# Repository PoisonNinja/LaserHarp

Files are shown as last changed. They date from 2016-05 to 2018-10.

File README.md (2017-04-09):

# Laser Harp
Code for creating a laser harp (school project)

# Setup
Only supported on systems with apt-get for now!
`./setup.sh`

# Usage
Connect the Arduino to the computer, and flash the code. Run `./connect.sh`, and hear the sound. 

To kill the programs, in a seperate terminal window, run `./kill.sh`. Make sure that you run this before unplugging the Arduino, or else you may experience sound glitches.

# MidiTest
A small utility to test out if MIDI is working or not.

You should hear a piano scale going upwards.

# MidiLEDSensor
Test code to control MIDI using a LED as a light sensor.

Wire a LED into the Arduino as follows:
* A5 to the short leg of the LED
* Resistor from the long leg to another part of the breadboard
* Breadboard/resistor to GND

Make sure you are in a bright room, and cover the LED. You should a piano tone.

If you want to use a different analog port, change the LEDPORT define. To change the note, change the NOTE define. To change the delay, change the DELAY define. To change the sensitivity of the LED, change the THRESHOLD define.

# MotorLaser
Code for the failed frameless harp idea. Currently is able to pulse the laser on and off in sync with the motor, drawing eight dots on the ceiling, and also has some code for reading detected sensor values. If you have a strong enough laser, this may work for you.

Wiring diagrams will have to be figured out by yourself, because I lost the diagrams.

Expected output is that it should play a note corresponding to the beam being cut.

# Guzheng
The code for our final project. The harp looks like the Chinese Guzheng, and was mainly inspired by it. It works well (assuming you built correctly), and has very little issues. It does have some latency, but it's very small.

A basic wiring diagram is available in the Guzheng folder, but it is incomplete, and you will have to figure out the rest of it.

Expected output is that it should play a note corresponding to the beam being cut.

# Harp
An experimental rewrite of the Guzheng code, except with a client-server architecture. This offloads most of the work to the computer and makes the Arduino a sensor hub, hopefully improving performance. It doesn't really work right now because it has a weird tendency to skip notes or hold on to notes too long.

Wiring diagrams and expected output are the same as the Guzheng.

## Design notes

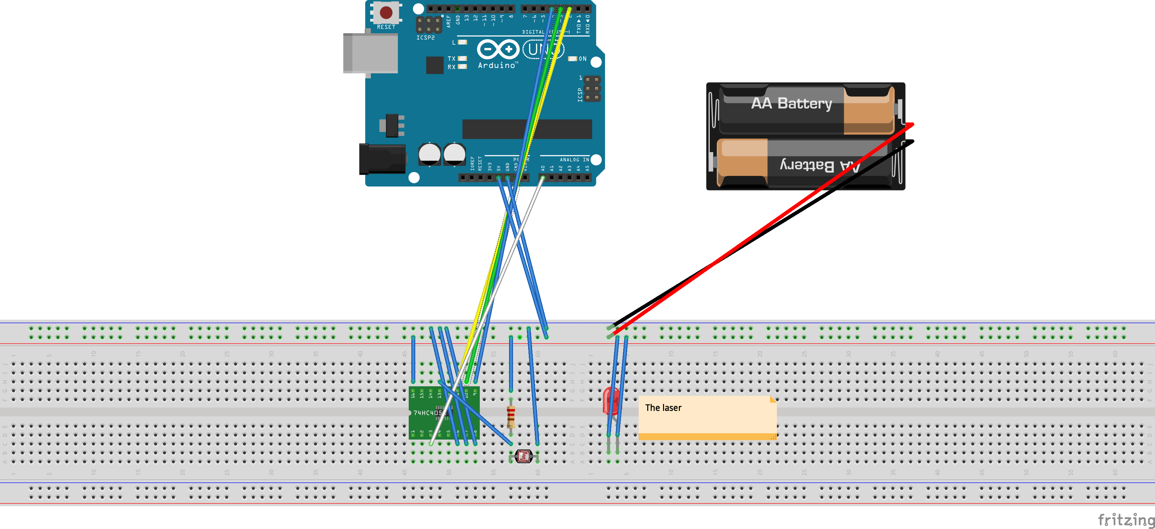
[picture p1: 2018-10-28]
Guzheng/Guzheng.png

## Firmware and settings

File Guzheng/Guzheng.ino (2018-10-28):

/* Code for laser guzheng
   Copyright (C) 2016 Jason Lu

   Licensed under the MIT License
   This code has NO WARRANTY! You are
   responsible for anything that happens
*/

// Port I/O defines
#define THRESHOLD 700
#define LASTPORT 7
#define INSTRUMENTBUTTON 8
#define NOTEBUTTON 9

// This works around the faulty fourth sensor
#define SENSOR_FIX

// MIDI property defines
#define VOLUME 0x7F

// Debounce threshold (milliseconds)
#define DEBOUNCE_THRESHOLD 100

/* Comment out the below to enable a slight delay between reading
   each note. This may be necessary because sometimes rapidly reading
   analog values can cause strange values. Comment out the below if
   you notice anything strange, because this is probably the culprit */
#define NODELAY

#ifndef NODELAY
#define DELAY 10
#endif

// MIDI Instrument Array
#define NUMINSTRUMENTS 6

// MIDI command defines
#define NOTEON 0x90
#define NOTEOFF 0x80
#define CHANGEINSTRUMENT 0xC0

// Values for different notes
// Currently a C scale, starting from middle C (C4)
#define note1 0x3C
#define note2 0x3E
#define note3 0x40
#define note4 0x41
#define note5 0x43
#define note6 0x45
#define note7 0x47
#define note8 0x48

// A minor scale
#define note9 0x39
#define note10 0x3B
#define note11 0x3C
#define note12 0x3E
#define note13 0x40
#define note14 0x41
#define note15 0x43
#define note16 0x45

int r0 = 0;
int r1 = 0;
int r2 = 0;

int noteSet = 0;

int instrumentButtonState = 0;
int noteButtonState = 0;
int currentInstrument = 0;

bool start = false;

// Piano, Harpsichord, Pizzacato strings, Flute, Violin, Accordian
// Sounds provided by MIDI synthesizer, so you may need to install it
int instrumentArray[NUMINSTRUMENTS] = {0x01, 0x07, 0x2E, 0x4A, 0x29, 0x16};

/* Flag values for each laser. These values will operate on the bit
   levels, directly with binary. They work together with the
   lastNote variable to keep track of blocked lasers.
   Here, I use an AND operator to read if the value has been
   set, and OR to set the value. */
uint8_t laserArray[8] = {0x01, 0x02, 0x04, 0x08, 0x10, 0x20, 0x40, 0x80};

/* Variable to keep track of the last played instrument. The real
   data shows up when converted to binary, since we use binary
   operator tricks. When the first laser is hit, it is 00000001. If
   the second one is hit, then it is 00000010, and the third one is
   00000100, and so on. */
uint8_t lastNote = 0;

unsigned long debounce[8] = {0};

// Function to write notes over serial
void noteOn(int cmd, int pitch, int velocity) {
  // MIDI command ID, such as 0x80 (note off) or 0x90 (note on)
  Serial.write(cmd);
  // MIDI note pitch, such as 0x3C (C)
  Serial.write(pitch);
  // MIDI note volume, from 0x00 (mute) to 0x7F (max)
  Serial.write(velocity);
}

// Function for playing note based on ID
void musicOn(int ID) {
  if (noteSet == 0) {
    switch (ID) {
      case 0:
        noteOn(NOTEON, note1, VOLUME);
        break;
      case 1:
        noteOn(NOTEON, note2, VOLUME);
        break;
      case 2:
        noteOn(NOTEON, note3, VOLUME);
        break;
      case 3:
        noteOn(NOTEON, note4, VOLUME);
        break;
      case 4:
        noteOn(NOTEON, note5, VOLUME);
        break;
      case 5:
        noteOn(NOTEON, note6, VOLUME);
        break;
      case 6:
        noteOn(NOTEON, note7, VOLUME);
        break;
      case 7:
        noteOn(NOTEON, note8, VOLUME);
        break;
      default:
        // WTF? It shouldn't reach here, because that's an invalid ID
        noteOn(NOTEOFF, note1, 0x00);
        break;
    }
  } else if (noteSet == 1) {
    switch (ID) {
      case 0:
        noteOn(NOTEON, note9, VOLUME);
        break;
      case 1:
        noteOn(NOTEON, note10, VOLUME);
        break;
      case 2:
        noteOn(NOTEON, note11, VOLUME);
        break;
      case 3:
        noteOn(NOTEON, note12, VOLUME);
        break;
      case 4:
        noteOn(NOTEON, note13, VOLUME);
        break;
      case 5:
        noteOn(NOTEON, note14, VOLUME);
        break;
      case 6:
        noteOn(NOTEON, note15, VOLUME);
        break;
      case 7:
        noteOn(NOTEON, note16, VOLUME);
        break;
      default:
        // WTF? It shouldn't reach here, because that's an invalid ID
        noteOn(NOTEOFF, note1, 0x00);
        break;
    }
  }
}

// Function for turning off a specific note based on ID
// Just a slightly modified version of musicOn()
void musicOff(int ID) {
  if (noteSet == 0) {
    switch (ID) {
      case 0:
        noteOn(NOTEOFF, note1, 0x7F);
        break;
      case 1:
        noteOn(NOTEOFF, note2, 0x7F);
        break;
      case 2:
        noteOn(NOTEOFF, note3, 0x7F);
        break;
      case 3:
        noteOn(NOTEOFF, note4, 0x7F);
        break;
      case 4:
        noteOn(NOTEOFF, note5, 0x7F);
        break;
      case 5:
        noteOn(NOTEOFF, note6, 0x7F);
        break;
      case 6:
        noteOn(NOTEOFF, note7, 0x7F);
        break;
      case 7:
        noteOn(NOTEOFF, note8, 0x7F);
        break;
      default:
        // WTF? It shouldn't reach here, because that's an invalid ID
        noteOn(NOTEOFF, note1, 0x00);
        break;
    }
  } else if (noteSet == 1) {
    switch (ID) {
      case 0:
        noteOn(NOTEOFF, note9, VOLUME);
        break;
      case 1:
        noteOn(NOTEOFF, note10, VOLUME);
        break;
      case 2:
        noteOn(NOTEOFF, note11, VOLUME);
        break;
      case 3:
        noteOn(NOTEOFF, note12, VOLUME);
        break;
      case 4:
        noteOn(NOTEOFF, note13, VOLUME);
        break;
      case 5:
        noteOn(NOTEOFF, note14, VOLUME);
        break;
      case 6:
        noteOn(NOTEOFF, note15, VOLUME);
        break;
      case 7:
        noteOn(NOTEOFF, note16, VOLUME);
        break;
      default:
        // WTF? It shouldn't reach here, because that's an invalid ID
        noteOn(NOTEOFF, note1, 0x00);
        break;
    }
  }
}

void setup()
{
  // Initialize serial at 115200 baud
  Serial.begin(115200);
  // Set the 74HC4051 command ports
  pinMode(2, OUTPUT);
  pinMode(3, OUTPUT);
  pinMode(4, OUTPUT);
  // Wait for a button press to start the loop, because
  // delaying can either be too short or too long, and
  // Hairless-MIDI (Windows) can't properly handle malformed
  // MIDI commands.
  while (!start) {
    if (digitalRead(INSTRUMENTBUTTON) == HIGH) {
      start = true;
      break;
    } else {
      delay(100);
    }
  }
}

void loop()
{
  // Main loop
  // LASTPORT+1 ports, from 0 to LASTPORT
  for (int i = 0; i <= LASTPORT; i++) {
    /* The following three lines convert the port we want
       into the correct bit selections for the 74HC4051. I'm
       not really sure exactly how it works, but I'm pretty
       sure it's some bit shifting
    */
    r0 = bitRead(i, 0);
    r1 = bitRead(i, 1);
    r2 = bitRead(i, 2);
    // Select the correct input using the values we calculated above
    digitalWrite(2, r0);
    digitalWrite(3, r1);
    digitalWrite(4, r2);
    // Detect if the instrument selection button is pressed
    if (digitalRead(INSTRUMENTBUTTON) == HIGH) {
      /* Make sure that this is the first time that the button
         has been pressed
      */
      if (instrumentButtonState == 0) {
        if (currentInstrument >= (NUMINSTRUMENTS - 1)) {
          // Max number of instruments, so wrap around to 0
          currentInstrument = 0;
        } else {
          // Select next instrument
          currentInstrument++;
        }
        // Send MIDI command to change instrument
        Serial.write(CHANGEINSTRUMENT);
        // Write the current instrument
        Serial.write(instrumentArray[currentInstrument]);
        // Set the button state so this won't fire when holding down
        // the button
        instrumentButtonState = 1;
      }
    } else {
      // Button is no longer pressed, so reset the button state.
      instrumentButtonState = 0;
    }
    // Detect if note button has been pressed
    if (digitalRead(NOTEBUTTON) == HIGH) {
      // Make sure that this is the first time that the button
      // has been pressed
      if (noteButtonState == 0) {
        // Swap the current note set
        // TODO: Figure out a better way to do this
        noteSet = !noteSet;
        noteButtonState = 1;
      }
    } else {
      // Button is no longer pressed, so reset the button state.
      noteButtonState = 0;
    }
    if ((millis() - debounce[i]) > DEBOUNCE_THRESHOLD) {
#ifdef SENSOR_FIX
      int threshold = (i == 3) ? 950 : THRESHOLD;
      if (analogRead(0) > threshold) {
#else
      if (analogRead(0) > THRESHOLD) {
#endif
        /* Apply the AND operator to the lastNote indicator and the
           corresponding value from the laser array to check if the
           laser bit has been set or not

           If it returns a non zero value, then that means it is set.
           If it is a zero, then the bit has not been set yet */
        if (!(lastNote & (laserArray[i]))) {
          debounce[i] = millis();

          // Beam has been cut
          musicOn(i);
          /* Set the bit using the OR operator between lastNote and
             the corresponding value from the laser array */
          lastNote |= (laserArray[i]);
        }
      } else {
        /* Check if the last note bit has been set or not using the
           AND operator. This won't always be true because this section
           of the code runs even if the beam hasn't been cut yet */
        if ((lastNote & (laserArray[i]))) {
          debounce[i] = millis();
          /* Unset the flag using the AND and invert operators */
          lastNote &= ~(laserArray[i]);
        }
        // Hand is gone. Stop the sound
        musicOff(i);
      }
#ifndef NODELAY
      // Delay 10 to prevent weird analog readings
      delay(DELAY);
#endif
    }
  }
}

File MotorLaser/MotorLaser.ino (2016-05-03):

/* Code for motor based laser harp
 * Copyright (C) 2016 Jason Lu
 *
 * Some code was taken from stepper motor sample code
 *
 */

/*-----( Import needed libraries )-----*/
#include <Stepper.h> 

#define lightPin 5
#define laserPin 7
#define motorDelay 4
#define laserDelay 0
#define threshold 70
#define motorSpeed 700
#define stepSize 2

int note9 = 0x61;
int note8 = 0x63;
int note7 = 0x64;
int note6 = 0x66;
int note5 = 0x68;
int note4 = 0x70;
int note3 = 0x71;
int note2 = 0x40;
int note1 = 0x47;

Stepper small_stepper(32, 8, 10, 9, 11);

int  Steps2Take;
int current;
int stepID;
int light;

void setup()   /*----( SETUP: RUNS ONCE )----*/
{
  // Nothing  (Stepper Library sets pins as outputs)
  Serial.begin(115200);
  pinMode(laserPin, OUTPUT);
}/*--(end setup )---*/

void parsePosition() {
  switch (stepID) {
  case 1:
    noteOn(0x90, note1, 0x7F);
    break;
  case 2:
    noteOn(0x90, note2, 0x7F);
    break;
  case 3:
    noteOn(0x90, note3, 0x7F);
    break;
  case 4:
    noteOn(0x90, note4, 0x7F);
    break;
  case 5:
    noteOn(0x90, note5, 0x7F);
    break;
  case 6:
    noteOn(0x90, note6, 0x7F);
    break;
  case 7:
    noteOn(0x90, note7, 0x7F);
    break;
  case 8:
    noteOn(0x90, note8, 0x7F);
    break;
  default:
    noteOn(0x90, note1, 0x00);
    break;
  }
}       

void loop()   /*----( LOOP: RUNS CONSTANTLY )----*/
{
  for (int i = 1; i < 8; i++) {
    digitalWrite(laserPin, LOW);
    small_stepper.setSpeed(motorSpeed);
    small_stepper.step(stepSize);
    stepID = i;
    delay(motorDelay);
    digitalWrite(laserPin, HIGH);
    delay(laserDelay);
    light = analogRead(lightPin);
    //    if (light > threshold) {
    //      parsePosition();
    //    } else {
    //      noteOn(0x90, 0x1E, 0x00);
    //    }
    Serial.print("ID: ");
    Serial.print(stepID);
    Serial.print(" Value: ");
    Serial.println(light);
  }
  // delay(1000);
  for (int i = 8; i > 1; i--) {
    digitalWrite(laserPin, LOW);
    small_stepper.setSpeed(motorSpeed);
    small_stepper.step(-stepSize);
    stepID = i;
    delay(motorDelay);
    digitalWrite(laserPin, HIGH);
    delay(laserDelay);
    light = analogRead(lightPin);
    //    if (light > threshold) {
    //      parsePosition();
    //    } else {
    //      noteOn(0x90, 0x1E, 0x00);
    //    }
    Serial.print("ID: ");
    Serial.print(stepID);
    Serial.print(" Value: ");
    Serial.println(light);
  }
  // delay(2000);

}/* --(end main loop )-- */

void noteOn(int cmd, int pitch, int velocity) {
  Serial.write(cmd);
  Serial.write(pitch);
  Serial.write(velocity);
}

/* ( THE END ) */

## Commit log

2016-04-23 Automatically install Arduino and Arduino-core
2016-04-28 Add actual motor code
2016-05-03 Replace hardcoded values with #defines
    [Guzheng.ino]
2016-05-03 Add note set switching capabilities
2016-05-03 Various updates
    Added license header, updated documentation. Also, added a new feature
    that prevents multiple hits when holding down a laser. Previously, it
    would play the sound over and over, which is OK for a wind instrument,
    but horrible for string and piano instruments.
    This commit adds a variable and related code to keep track of the last
    hit laser, which causes it to play the sound once, even if the laser is
    held down.
    Also added are some #ifndefs that disable the new code when #define WIND
    is uncommented. This reverts this program back to the old behavior.
    [Guzheng.ino]
2016-05-04 Fix multiple hit detection
    [Guzheng.ino]
2016-05-04 Revert "Add note set switching capabilities"
    This reverts commit 14bdc8510426fa06bfbe9dd548d83b6c2d706097.
    [Guzheng.ino]
2016-05-04 Support for multiple strings in multiple hit detection
    Previously, the instrument would revert to the old behavior of repeatedly
    playing the same notes when holding a string down, which is wrong. This
    was a limitation of the way that we tracked the last held string, which
    only supports tracking one string at a time. However, when you held two
    strings, what would happen is the last string tracker would switch back
    and forth, rendering it useless.
    This commit replaces the old system with a new one based on bitwise
    operations and flags to keep track. The last string tracker is now just
    a tracker in general, as it is an unsigned int. Each laser has it's own
    flag assigned, with laser1 as 0x01, l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
    [Guzheng.ino]
2016-05-05 Fix new flag code
    Fixed some bugs, such as one-off bugs and logic errors
    [Guzheng.ino]
2016-05-09 Various updates
    Changed capitalization for comment
    Enabled support for 8 laser beams
    Changed inttomask to an array, which offers better performance. This also
    saves us the cost of having to calculate i + 1, since arrays are also 0
    indexed.
2016-05-10 Switch functions to zero-indexed
2016-05-11 First pass at button handling
    Implemented a system similar to the laser rejection code for the button
    to prevent multiple button clicks when held down.
    Button switches the instrument to a trumpet.
    [Guzheng.ino]
2016-05-11 Replace trumpet with string pizz
    [Guzheng.ino]
2016-05-11 Use array for instruments
    Use an array to store instruments, allowing us to cycle between instruments
    with the press of a button. The nice thing is you can add more instruments
    relatively easily, as long as timidity supports it.
    If timidity has no output, you may need to install an extended sound font
    for timidty, such as Fluid General MIDI SoundFont
    This commit also fixes some glitches with button presses, although this code
    is likely to not work, because it has not been tested on real hardware.
    [Guzheng.ino]
2016-05-12 Add note set switching support
    Uses another button that allows us to switch octaves
2016-05-12 Rename button variables
2016-05-17 Add wiring for Guzheng
    [Guzheng.fzz]
2016-05-20 Support for switching music set
2016-05-20 New server/client scheme for harps
    Most processing is done on the computer now, to reduce latency when blocking a laser.
2016-05-20 Remove harp code
    Doesn't work
    [client.ino]
2016-05-21 Wait for button press to start
    Wait for button press before launching rest of the code, to avoid
    causing Hairless MIDI to crash because of bad data. ttymidi doesn't have
    this problem.
    [Guzheng.ino]
2016-05-23 Revert "Remove harp code"
    This reverts commit fc093578bbda0462772f6322f3f2ab65b20340cf.
    [client.ino]
2016-05-23 Replace if with boolean invertion
    Removes the need for a slightly more costly if-else statement
    [Guzheng.ino]
2018-10-28 Add faulty sensor hack
2018-10-28 Fix Guzheng wiring diagrams
    [Guzheng.fzz]
